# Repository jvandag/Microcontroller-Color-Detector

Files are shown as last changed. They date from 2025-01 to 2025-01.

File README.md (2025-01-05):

# Microcontroller-Color-Detector
Detects the color of physical objects using a phototransistor and simple machine learning.

## Pre-trained Example
Once the color detector has a full set of training data the user can scan a color using the blue button. The scan data is then compared against the training data to find the closest color match.

https://github.com/user-attachments/assets/66921391-efe7-4fe2-914a-f40178192495

## Training menu
The prompt to swap to training mode can be entered by pressing the yellow button. Once in training mode, additional samples may be taken the same way you would scan a color with the blue button. While in training mode, both buttons may be pressed at once to prompt deleting the stored training data. Each color requires 12 samples to function properly. If scanning/ready mode is entered when there is not sufficient training data, a message will display the colors that need more samples. 

https://github.com/user-attachments/assets/d95f9c35-6fea-4ae8-9513-e3b5f32a4a7d

## Circuit Diagram
The following circuit diagram is the one used in the example videos. Most microcontrollers that can run arduino code and have sufficient memory as well as two processing cores should have no problem replacing the [Adafruit ESP32 Feather V2]([url](https://learn.adafruit.com/adafruit-esp32-feather-v2)) that was used in the example. 

**Some things to note if using a different microcontroller:**
- Your analog resolution may be different so make sure to set the [ANALOG_RES]([url](https://github.com/jvandag/Microcontroller-Color-Detector/blob/ead716868bf5c02b5b45c210d8dfff97584aa8df/protos_and_consts.h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)) macro to your microcontroller's analog resolution.
- The example microcontroller has an internal pull up and pull down buttons that don't have resistors on the ground path. This is fine in this case but make sure that this wont fry your microcontroller or use pull down resistors.
- You may also have a similar problem with the LEDs. The out put on the example microcontroller output 3.3V to each LED which is a little high for some of them. You definitely should use resistors here if you have a higher voltage microcontroller.

Lastly, the 4 mega-ohm pull down on the photo transistor should be adjusted to fit your particular 3D print and microcontroller. If you find your phototransistor readings are too high, use a smaller pull down resistance. __I would highly recommend design your own case instead of using the stl files in this repository.__ The model is a bit small making it difficult to fit all of the components into the case and uncomfortable to hold the device as the grip area is too small. Additionally, bottom section that shields the transistor from external light is to long. In the example videos this section was 3mm from the paper to where the phototransistor was mounted, using a smaller distance would provide better readings, especially if you're using regular LEDs like the example.

circuit_diagram

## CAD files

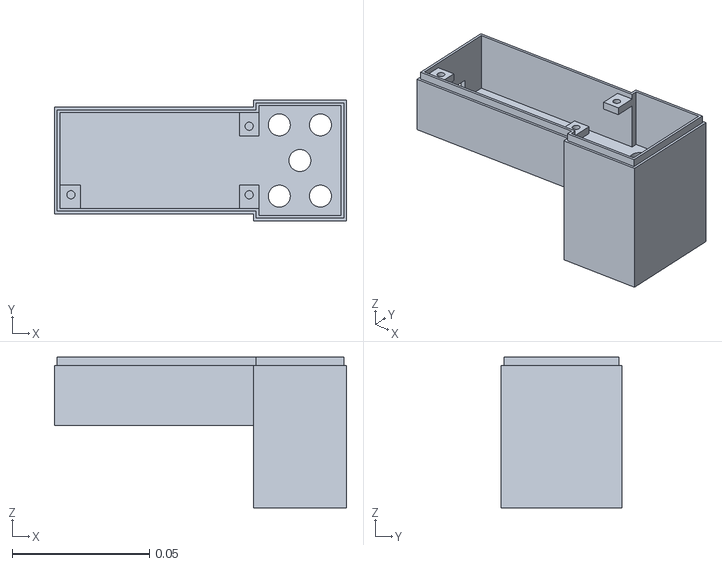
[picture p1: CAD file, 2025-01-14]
case_bottom.stl
0.106 x 0.044 x 0.055

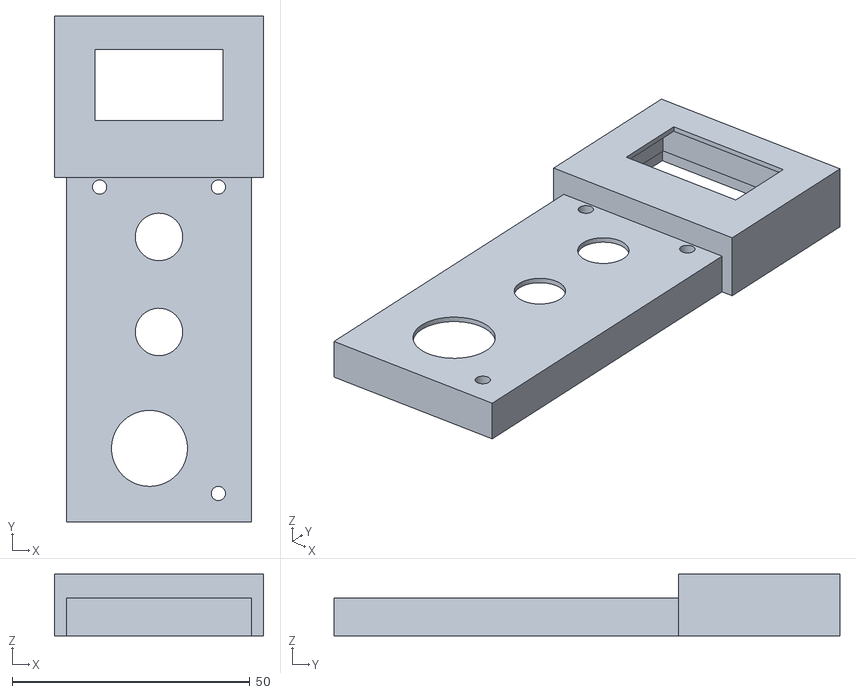
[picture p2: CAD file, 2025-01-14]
case_top.stl
44.0 x 106.5 x 13.0

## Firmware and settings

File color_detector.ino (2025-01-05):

#include <Adafruit_GFX.h>
#include <Adafruit_SSD1306.h>
#include <SPI.h>
#include <SD.h>
#include <math.h>
#include "protos_and_consts.h"
#include "screen_bitmaps.h"

// User Input
int selectPos    = 1024 * (analogRead(POTENTIOMETER_PIN)) / ANALOG_RES;
bool btn1Val     = true; // false when pressed (pull down btn)
bool btn2Val     = true; // false when pressed (pull down btn)
bool btn1LastVal = true; 
bool btn2LastVal = true;

//OLED SCREEN PARAMETERS
int LOADING_FRAME_COUNT = (sizeof(loading_frames) / sizeof(loading_frames[0]));

Adafruit_SSD1306 display(128, 64, &Wire, OLED_RST_PIN);

unsigned long t;
unsigned long time_checkpoint;
int loadingMenuFrame  = 0;
int textX = 0, textY  = 0;  // Text position
String text           = "";
bool select_screen    = true;
bool scrolling        = false;
bool scroll_end       = true;
bool scroll_start     = true;
int current_menu      = 0;
bool YesNoSel         = false;
int charWidth         = 6; 


// MISC
String logMsg                   = "";
bool quit                       = false;
int lastTrainedColor            = -1;
unsigned long lastLogMsgUpdate  = -1;
bool awaitingUsrSel             = false;
String notEnoughSamples         = "";
int pot_val;


// Data Containers

//Indicates wether each category has enough samples
int sampleCounts[8] = {0};

struct sample {
  //A sample of the values read by the phototransistor from the colored LEDs
  unsigned int groupValue : 3;            //We only need 3 bits to categorize 6 groups
  uint8_t colorValues[NUM_COLOR_VALUES];
  unsigned int distance : 11;             //The biggest distance can be 2046 units

  //Overloading the equal operator to set all values of one sample equal to another sample
  sample &operator=(const sample &s) {
    for (int a = 0; a < NUM_COLOR_VALUES; a++) {
      colorValues[a] = s.colorValues[a];
    }
    distance = s.distance;
    groupValue = s.groupValue;
    return *this;
  }
};

struct Group {
  unsigned int id : 3;         //There are only 8 groups, so we only need 3 bits
  unsigned int frequency : 4;  //We're limiting it to 12 samples per group, and 4 bits give us 15
};

struct {
  //Used to keep track of global memory in a tight compartment
  unsigned char trainingModeActive : 1;  //Basically a boolean
  unsigned char currentlyReading : 1;    //Debounce for button press
  unsigned char loadingRequired : 1;     //When we flip the toggle switch to sampling, we need to load the data
  unsigned int selectedGroupId : 4;      //What's the potentiometer pointing to?
  sample trainingData[8 * SAMPLES_PER_GROUP];
} colorDetector;



// Creating a process for each core
TaskHandle_t DisplayLoopHandle = NULL;
TaskHandle_t DataProcessingLoopHandle = NULL;

void setup() {
  Serial.begin(9600);
  while (!Serial) {
    delay(10);
  }
  pinMode(BTN1, INPUT_PULLUP);
  pinMode(BTN2, INPUT_PULLUP);
  pinMode(POTENTIOMETER_PIN, INPUT);
  pinMode(PHOTOTRANSISTOR_PIN, INPUT);
  pinMode(YELLOW_LED, OUTPUT);
  pinMode(GREEN_LED, OUTPUT);
  pinMode(RED_LED, OUTPUT);
  pinMode(BLUE_LED, OUTPUT);

  if (!SD.begin(CS_PIN)) {
    Serial.println("Card Mount Failed");
    return;
  } else {
    getDataFromCard();
    listDir(SD, "/", 0);
  }

  pot_val = analogRead(POTENTIOMETER_PIN);
  colorDetector.trainingModeActive = 0;
  checkMinNumSamples();
  current_menu = READY;

  // Create tasks and pin them to specific cores
  xTaskCreatePinnedToCore(
    displayLoop,          // Task function
    "Display Loop Task",  // Name of the task
    12000,                // Stack size for the task in words (num bytes / 4)
    NULL,                 // Parameter to pass to the task
    2,                    // Task priority
    &DisplayLoopHandle,   // Task handle
    1                     // Core ID (1 for Core 1)
  );

  xTaskCreatePinnedToCore(processingLoop, "Data Processing Loop Task", 12000, NULL, 2, &DataProcessingLoopHandle, 0);
}

void loop() {}

void displayLoop(void *parameter) {
  if (!display.begin(SSD1306_SWITCHCAPVCC, SCREEN_I2C_ADDR)) {
    Serial.println("SSD1306 allocation failed");
    vTaskDelete(NULL);  // End the task if display initialization fails
  }

  String t_text = "Training:";
  int offset;
  
  while (true) {
    display.clearDisplay();
    t = millis();
    pot_val = analogRead(POTENTIOMETER_PIN);

    if (colorDetector.trainingModeActive && !awaitingUsrSel && current_menu != LOADING) {
      if (t - lastLogMsgUpdate < 2000 && logMsg.length() > 0) {
        drawTextAtPosition(0, 0, logMsg, true, 1.5);
      }
      else if (colorDetector.trainingModeActive && current_menu != LOADING) {
        drawTextAtPosition(0, 0, t_text, true, 1.5);
      }
    }
    switch (current_menu) {
      case DET_BLACK:
      case DET_WHITE: 
      case DET_RED:
      case DET_ORANGE:
      case DET_YELLOW:
      case DET_GREEN:
      case DET_BLUE:
      case DET_PURPLE:
        displayDetColorText();
        break;
      case READY:
        displayReady();
        break;
      case ENABLE_TRAINING:
      case DISABLE_TRAINING:
      case DEL_TRAINING:
        displayYesNoOpt();
        break;
      case COLOR_LOGGED:
      case COLOR_SEL: 
        offset = getOffset(selectPos);
        drawSelMenuSlice(offset);
        break;
      case LOADING:
        displayLoading();
        break;
      default: break;
    }

    display.display();
    // Delay to yield to the OS and avoid watchdog issues
    vTaskDelay(15 / portTICK_PERIOD_MS);
  }
}

void processingLoop(void *parameter) {
  bool btn1LastState = true;
  bool btn2LastState = true;

  while(true) {
    btn1Val = digitalRead(BTN1);
    btn2Val = digitalRead(BTN2);

    if(awaitingUsrSel) {
      if(!btn1Val && btn1LastState) {
        if (YesNoSel) {
          switch(current_menu) {
            case ENABLE_TRAINING:
            case DISABLE_TRAINING:
              checkMinNumSamples();
              colorDetector.trainingModeActive = !colorDetector.trainingModeActive;
              current_menu = colorDetector.trainingModeActive ? COLOR_SEL : READY;
              break;
            case DEL_TRAINING: 
              deleteTraining(SD);
              colorDetector.trainingModeActive = 1;
              current_menu = COLOR_SEL;
              break;
            default: 
              current_menu = COLOR_SEL;
              break;
          }
          
        }
        else current_menu = colorDetector.trainingModeActive ? COLOR_SEL : READY;
        awaitingUsrSel = false;
      }
      else if (!btn2Val && btn2LastState) {
        current_menu = colorDetector.trainingModeActive ? COLOR_SEL : READY;
        awaitingUsrSel = false;
      }
      btn1LastState = btn1Val;
      btn2LastState = btn2Val;
      continue;
    }
    
    // If one button is pressed wait a moment to see if the user is
    // trying to press both buttons at once
    if(btn1Val && !btn2Val) {
      vTaskDelay(100 / portTICK_PERIOD_MS);
      btn1Val = digitalRead(BTN1);
    }
    else if (!btn1Val && btn2Val) {
      vTaskDelay(100 / portTICK_PERIOD_MS);
      btn2Val = digitalRead(BTN2);
    }
    
    if (current_menu != LOADING && btn1Val && !btn2Val && btn2LastState) {
      //change bring up toggle training mode menu
      current_menu = (colorDetector.trainingModeActive || current_menu == DISABLE_TRAINING) ? DISABLE_TRAINING : ENABLE_TRAINING;
      awaitingUsrSel = true;
      btn1LastState = btn1Val;
      btn2LastState = btn2Val;
      //add delay between checks
      vTaskDelay(15 / portTICK_PERIOD_MS);
      continue;
    }
    else if (current_menu != LOADING && colorDetector.trainingModeActive && !btn1Val && !btn2Val) {
      //change bring up toggle training mode menu
      current_menu = DEL_TRAINING;
      awaitingUsrSel = true;
      btn1LastState = btn1Val;
      btn2LastState = btn2Val;
      //add delay between checks
      vTaskDelay(15 / portTICK_PERIOD_MS);
      continue;
    }

    if (!btn1Val && btn1LastState && !colorDetector.currentlyReading && !scrolling) {
      if (colorDetector.trainingModeActive) {
        colorDetector.currentlyReading = 1;
        current_menu = LOADING;
        //When we click the button we will store the data into the selected group's file on the SD card
        const String path = String("/") + String(colorDetector.selectedGroupId) + String(".txt");
        //Since we added to the training data, we need to load that new data next time we sample
        colorDetector.loadingRequired = 1;
        //Write color data to SD card in RGBY order
        writeColor(RED_LED, SD);
        writeColor(GREEN_LED, SD);
        writeColor(BLUE_LED, SD);
        writeColor(YELLOW_LED, SD);
        appendFile(SD, path, "\n");

        sampleCounts[colorDetector.selectedGroupId]++;

        // Sleep to let our nice loading animation play for a moment :')
        vTaskDelay(LOADING_DELAY / portTICK_PERIOD_MS);
        current_menu = COLOR_SEL;
        lastLogMsgUpdate = millis();
        logMsg = color2Txt(colorDetector.selectedGroupId) + " Sample Logged!";
      } 
      else if (notEnoughSamples == "") {
        //When we click the button we will compare the sample data to the training data
        current_menu = LOADING;

        sample newSample;
        Serial.printf("Red ");
        newSample.colorValues[0] = readColor(RED_LED);
        Serial.printf("Green ");
        newSample.colorValues[1] = readColor(GREEN_LED);
        Serial.printf("Blue ");
        newSample.colorValues[2] = readColor(BLUE_LED);
        Serial.printf("Yellow ");
        newSample.colorValues[3] = readColor(YELLOW_LED);
        //If we haven't added anything new to the training data, we don't need to read from the SD card again
        if (colorDetector.loadingRequired) {
          //Take the training data from the SD card and put it into the trainingData array
          getDataFromCard();
          colorDetector.loadingRequired = 0;
        }
        //Now we use the classify() function to determine what color newSample is... but how many neighbors should we look at?
        //Typically you can get away with setting k to the square root of the total number of datapoints. In our case k=sqrt(8*12)
        int newSample_groupId = classify(colorDetector.trainingData, 8 * SAMPLES_PER_GROUP, 9, newSample);

        // Sleep to let our nice loading animation play for a moment :')
        vTaskDelay(LOADING_DELAY / portTICK_PERIOD_MS);
        current_menu = newSample_groupId;
        vTaskDelay(2000 / portTICK_PERIOD_MS);
        current_menu = READY;
      }
      colorDetector.currentlyReading = 0;
    }
    btn1LastState = btn1Val;
    btn2LastState = btn2Val;

    //loop delay
    vTaskDelay(10 / portTICK_PERIOD_MS);
  }
}

void checkMinNumSamples() {
  String lastColor = "";
  notEnoughSamples = "";
  int notEnoughCount = 0;

  for (int i = 0; i < 8; i++) {
    if (sampleCounts[i] < 12) {
      // If there are already elements in notEnoughSamples, handle commas and spaces
      if (notEnoughCount > 0) {
        if (notEnoughCount == 1) {
          notEnoughSamples += lastColor; // Add the first color without a comma
        } else {
          notEnoughSamples += ", " + lastColor; // Add comma for subsequent colors
        }
      }
      lastColor = color2Txt(i); // Update lastColor to the current color
      notEnoughCount++;
    }
  }

  // Handle final addition with "and"
  if (notEnoughCount > 1) {
     if (notEnoughCount == 2) {
      // No comma for exactly two entries
      notEnoughSamples += " and " + lastColor;
    } else {
      notEnoughSamples += ", and " + lastColor;
    }
  } else if (notEnoughCount == 1) {
    notEnoughSamples = lastColor; // Only one entry
  }
}



void displayReady() {
  if (notEnoughSamples != "") {
    drawTextAtPosition(0, 0, "Low Sample Count!", true, 1.5);
    drawTextAtPosition(0, 16, "The following need\nmore samples:\n\n" + notEnoughSamples, false, 1.5);
  } else {
    drawTextAtPosition(0, 0, "Press the blue button", true, 1.5);
    drawTextAtPosition(0, 8, "to scan.", true, 1.5);
    drawTextAtPosition(14, 26, "Ready!", false, 3.5);
  }
}

void displayLoading() {
  display.drawBitmap(40, 16, loading_frames[loadingMenuFrame], FRAME_WIDTH, FRAME_HEIGHT, 1);
  drawTextAtPosition(0, 0, getProcessingString(loadingMenuFrame), false, 1.5);

  // Update loadingMenuFrame
  loadingMenuFrame = (loadingMenuFrame + 1) % LOADING_FRAME_COUNT;
  delay(FRAME_DELAY);
}

void displayYesNoOpt() {
  //logMsg = "";
  // Draw the Yes and No text
  display.drawBitmap(0, 0, epd_bitmap_YesNoBitmap, SCREEN_WIDTH, SCREEN_HEIGHT, SSD1306_WHITE);
  // Display prompt text
  String prompt = "";
  switch (current_menu) {
    case ENABLE_TRAINING: 
      prompt = "Enable Training Mode?";
      break;
    case DISABLE_TRAINING:
      prompt = "Disable Training\nMode?";
      break;
    case DEL_TRAINING:
      prompt = "Delete All Training\nData?";
      break;
    default:
      prompt = "Unknown Prompt";
      break;
  }
  drawTextAtPosition(0, 0, prompt, false, 1.5);

  // Set the highlight
  YesNoSel = pot_val % ((ANALOG_RES+1)/2) <= ANALOG_RES/4;
  int rectWidth = 36;
  int rectHeight = 23;
  int radius = 10;
  if (YesNoSel) display.drawRoundRect(14, 27, rectWidth, rectHeight, radius, SSD1306_WHITE);
  else display.drawRoundRect(78, 27, rectWidth, rectHeight, radius, SSD1306_WHITE);
}

void displayDetColorText() {
  // Set these to true to disable blinky arrows when we slice the bitmap
  scroll_start = true;
  scroll_end = true;
  // Enable rounded rectangle boarder around text
  scrolling = false;

  int dispNum = (0 <= current_menu && current_menu < 8) ? current_menu : 0;
  // Get the bit map offset for slicing the color text out of the map
  int offset = SCREEN_WIDTH * dispNum;
  // Finally draw the text
  drawSelMenuSlice(offset);
  drawTextAtPosition(0, 0, "Color Detected:", true, 1.5);
}

String color2Txt(int color) {
  switch(color) {
    case black:   return "Black";
    case white:   return "White";
    case red:     return "Red";
    case orange:  return "Orange";
    case yellow:  return "Yellow";
    case green:   return "Green";
    case blue:    return "Blue";
    case purple:  return "Purple";
  }
}

void changeColor(enum colors c) {
  colorDetector.selectedGroupId = c;
}

// Function to draw text at a specified position
void drawTextAtPosition(int x, int y, String txt, bool center = false, float size = 1.5) {
  if (center) x = (SCREEN_WIDTH-charWidth*(size /1.5)*txt.length())/2;
  display.setTextSize(size);
  display.setCursor(x, y);
  display.setTextColor(SSD1306_WHITE);
  display.print(txt);
}

// returns the processing loading text with an appropriate number of dots
String getProcessingString(int num_frames) {
  //TO DO: Change to use current millis() instead of loadingMenuFrame
  String loading_text = "Processing";
  for (int i = 0; i < ((int)(num_frames / 7)) % 4; i++) {
    loading_text += ".";
  }
  return loading_text;
}

int getOffset(int &selectPos) {
  int val = pot_val * SEL_MAP_WIDTH / ANALOG_RES;
  scroll_start = scroll_end = false;
  scrolling = true;
  if (val > 7 * SCREEN_WIDTH) {
    changeColor(purple);
    if (selectPos < 7 * SCREEN_WIDTH) selectPos = min(selectPos + SEL_SCROLL_SPD, 7 * SCREEN_WIDTH);
    else if (selectPos > 7 * SCREEN_WIDTH) selectPos = max(selectPos - SEL_SCROLL_SPD, 7 * SCREEN_WIDTH);
    if (selectPos == 7 * SCREEN_WIDTH) {
      time_checkpoint = millis();
      scrolling = false;
    }
    scroll_end = true;
    return selectPos;
  }
  if (val > 6 * SCREEN_WIDTH) {
    changeColor(blue);
    if (selectPos < 6 * SCREEN_WIDTH) selectPos = min(selectPos + SEL_SCROLL_SPD, 6 * SCREEN_WIDTH);
    else if (selectPos > 6 * SCREEN_WIDTH) selectPos = max(selectPos - SEL_SCROLL_SPD, 6 * SCREEN_WIDTH);
    if (selectPos == 6 * SCREEN_WIDTH) {
      time_checkpoint = millis();
      scrolling = false;
    }
    return selectPos;
  }
  if (val > 5 * SCREEN_WIDTH) {
    changeColor(green);
    if (selectPos < 5 * SCREEN_WIDTH) selectPos = min(selectPos + SEL_SCROLL_SPD, 5 * SCREEN_WIDTH);
    else if (selectPos > 5 * SCREEN_WIDTH) selectPos = max(selectPos - SEL_SCROLL_SPD, 5 * SCREEN_WIDTH);
    if (selectPos == 5 * SCREEN_WIDTH) {
      time_checkpoint = millis();
      scrolling = false;
    }
    return selectPos;
  }
  if (val > 4 * SCREEN_WIDTH) {
    changeColor(yellow);
    if (selectPos < 4 * SCREEN_WIDTH) selectPos = min(selectPos + SEL_SCROLL_SPD, 4 * SCREEN_WIDTH);
    else if (selectPos > 4 * SCREEN_WIDTH) selectPos = max(selectPos - SEL_SCROLL_SPD, 4 * SCREEN_WIDTH);
    if (selectPos == 4 * SCREEN_WIDTH) {
      time_checkpoint = millis();
      scrolling = false;
    }
    return selectPos;
  }
  if (val > 3 * SCREEN_WIDTH) {
    changeColor(orange);
    if (selectPos < 3 * SCREEN_WIDTH) selectPos = min(selectPos + SEL_SCROLL_SPD, 3 * SCREEN_WIDTH);
    else if (selectPos > 3 * SCREEN_WIDTH) selectPos = max(selectPos - SEL_SCROLL_SPD, 3 * SCREEN_WIDTH);
    if (selectPos == 3 * SCREEN_WIDTH) {
      time_checkpoint = millis();
      scrolling = false;
    }
    return selectPos;
  }
  if (val > 2 * SCREEN_WIDTH) {
    changeColor(red);
    if (selectPos < 2 * SCREEN_WIDTH) selectPos = min(selectPos + SEL_SCROLL_SPD, 2 * SCREEN_WIDTH);
    else if (selectPos > 2 * SCREEN_WIDTH) selectPos = max(selectPos - SEL_SCROLL_SPD, 2 * SCREEN_WIDTH);
    if (selectPos == 2 * SCREEN_WIDTH) {
      time_checkpoint = millis();
      scrolling = false;
    }
    return selectPos;
  }
  if (val > SCREEN_WIDTH) {
    changeColor(white);
    if (selectPos < SCREEN_WIDTH) selectPos = min(selectPos + SEL_SCROLL_SPD, SCREEN_WIDTH);
    else if (selectPos > SCREEN_WIDTH) selectPos = max(selectPos - SEL_SCROLL_SPD, SCREEN_WIDTH);
    if (selectPos == SCREEN_WIDTH) {
      time_checkpoint = millis();
      scrolling = false;
    }
    return selectPos;
  } else {
    changeColor(black);
    if (selectPos < 0) selectPos = min(selectPos + SEL_SCROLL_SPD, 0);
    else if (selectPos > 0) selectPos = max(selectPos - SEL_SCROLL_SPD, 0);
    if (selectPos == 0) {
      time_checkpoint = millis();
      scrolling = false;
    }
    scroll_start = true;
    return selectPos;
  }
}

void drawSelMenuSlice(int xOffset) {
  // Ensure xOffset is within bounds of the larger bitmap
  xOffset = min(max(xOffset, 0), SEL_MAP_WIDTH - SCREEN_WIDTH);

  // Buffer for the sliced 128x48 image
  uint8_t slicedBitmap[SCREEN_WIDTH * SCREEN_HEIGHT / 8];

  // Copy the relevant section from the larger bitmap to the sliced bitmap
  for (int y = 0; y < SCREEN_HEIGHT; y++) {
    int sourceIndex = y * (SCREEN_WIDTH) + (xOffset / 8);  // Start byte of the row in the larger bitmap
    int targetIndex = y * (SCREEN_WIDTH / 8);          // Start byte of the row in the sliced bitmap

    // Copy exactly 16 bytes (128 pixels) for each row
    memcpy(&slicedBitmap[targetIndex], &epd_bitmap_color_sel_screen_bitmap[sourceIndex], SCREEN_WIDTH / 8);
  }

  // Draw the sliced bitmap on the display
  display.drawBitmap(0, 0, slicedBitmap, SCREEN_WIDTH, SCREEN_HEIGHT, SSD1306_WHITE);

  if (!scrolling) {
    // Define dimensions for the rectangle loadingMenuFrame
    int rectWidth = 94;   // Width of the rectangle
    int rectHeight = 40;  // Height of the rectangle
    int radius = 10;

    // Calculate the top-left corner to center the rectangle
    int x = (SCREEN_WIDTH - rectWidth) / 2;
    int y = (SCREEN_HEIGHT - rectHeight + 9) / 2;

    // Draw the rounded rectangle
    display.drawRoundRect(x, y, rectWidth, rectHeight, radius, SSD1306_WHITE);

    if (time_checkpoint % 1500 > 700) {
      int arrowSize = 6;                    // Size of the arrow head
      int yCenter = SCREEN_HEIGHT / 2 + 4;  // Center of the screen vertically

      if (!scroll_start) {
        // Draw < symbol on the left side
        display.drawLine(0, yCenter, 0 + arrowSize, yCenter - arrowSize, SSD1306_WHITE);  // Left top line
        display.drawLine(0, yCenter, 0 + arrowSize, yCenter + arrowSize, SSD1306_WHITE);  // Left bottom line
      }

      if (!scroll_end) {
        // Draw > symbol on the right side
        display.drawLine(SCREEN_WIDTH - 1, yCenter, SCREEN_WIDTH - 1 - arrowSize, yCenter - arrowSize, SSD1306_WHITE);  // Right top line
        display.drawLine(SCREEN_WIDTH - 1, yCenter, SCREEN_WIDTH - 1 - arrowSize, yCenter + arrowSize, SSD1306_WHITE);  // Right bottom line
      }
    }
  }
}

void insertionSort(sample arr[], int n) {
  // Copied and modified from GeeksForGeeks.com
  int i, key, j;
  for (i = 1; i < n; i++) {
    key = arr[i].distance;
    j = i - 1;

    while (j >= 0 && arr[j].distance > key) {
      sample temp = arr[j + 1];
      arr[j + 1] = arr[j];
      arr[j] = temp;
      j = j - 1;
    }
    arr[j + 1].distance = key;
  }
}

// Gets the biggest difference in color value
// Was found to work the best in my use case but suming all the differences in RGBY values
// will likely work better in most cases
unsigned int maxColorValueDistance(const sample &s1, const sample &s2) {
  unsigned int maxDifference = 0;
  for (int i = 0; i < 4; ++i) { // Assuming there are 4 color values
    unsigned int diff = std::abs(static_cast<int>(s1.colorValues[i]) - static_cast<int>(s2.colorValues[i]));
    if (diff > maxDifference) {
      maxDifference = diff;
    }
  }
  return maxDifference;
}
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

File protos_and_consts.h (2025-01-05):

#ifndef _PROTOS_AND_CONSTS_H
#define _PROTOS_AND_CONSTS_H

// PINs
#define BTN1 14 // K10 on board
#define BTN2 15 // M10 on board
#define POTENTIOMETER_PIN 13 // A12, Q1 on board
#define PHOTOTRANSISTOR_PIN A3
//#define BUTTON_PIN 2
#define RED_LED 33 
#define YELLOW_LED 12
#define GREEN_LED 27
#define BLUE_LED 25
//#define TOGGLE_SWITCH_PIN 19 //A5
#define OLED_RST_PIN -1  // Reset pin (-1 if not available)
#define CS_PIN 4 // SD card chip select


// OLED SCREEN PARAMETERS
#define SCREEN_I2C_ADDR 0x3C // or 0x3C
#define SCREEN_WIDTH 128     // OLED display width, in pixels
#define SCREEN_HEIGHT 64     // OLED display height, in pixels
#define FRAME_DELAY 42
#define FRAME_WIDTH 48
#define FRAME_HEIGHT 48
#define SEL_SCROLL_SPD 12
#define SEL_MAP_WIDTH 1024
#define SEL_SCR_COUNT 8

// MISC
#define ANALOG_RES 4095
#define LOADING_DELAY 1500
#define SAMPLES_PER_GROUP 12
#define NUM_COLOR_VALUES 4 //Red, blue, green, and yellow values


enum menus {
  DET_BLACK,
  DET_WHITE,
  DET_RED,
  DET_ORANGE,
  DET_YELLOW,
  DET_GREEN,
  DET_BLUE,
  DET_PURPLE,
  READY,
  ENABLE_TRAINING,
  DISABLE_TRAINING,
  DEL_TRAINING,
  COLOR_SEL,
  LOADING,
  COLOR_LOGGED,
};

enum colors {
  black,
  white,
  red,
  orange,
  yellow,
  green,
  blue,
  purple
};

// Checks if each color has atleast the minimum number of samples needed.
// Sets the string notEnoughSamples to a list of the groups that don't ahve enough samples
void checkMinNumSamples();

// Displays the loading screen
void displayLoading();

// displays the ready to scan screen
void displayReady();

// Returns the string name of the enum color
String color2Txt(int color);

// Sets the display to be a yes no option menu with prompt text based on the current_menu variable
void displayYesNoOpt();

// Sets the display to show the appropriate slice of the select menu bitmap when detecting a color
void displayDetColorText();

// Deletes a file at the given path
void deleteFile(fs::FS &fs, const String &path);

// Appends to the file at the given path, creates a new file if the file doesn't exist
void appendFile(fs::FS &fs, const String &path, const String &message);

// Overwrites a file at the given path, creates a new file if the file doesn't exist
void writeFile(fs::FS &fs, const char *path, const char *message);

// Lists the files in a directory on the SD card
void listDir(fs::FS &fs, const char *dirname, uint8_t levels);

// Gathers and writes color training data to the SD card
void writeColor(int pin, fs::FS &SD);

// Similar to writeColor() but doesn't write to the SD card
int readColor(int pin);

// Returns the number of digits in an integer
int getNumDigits(int num);

// Updates the current menu to prompt displayLoop to change the display to the color
void displayColor(colors color);

// Retrieves training data from the SD card and loads it into colorDetector.trainingData
void getDataFromCard();

/*
The classify() function utilizes the KNN algorithm
k is the number of nearby neighbors
*/
int classify(struct sample arr[], int numTrainingSamples, int k, const sample node);

//Takes two colorValue arrays and finds the distance between each color value.
//We're using the formula d=sqrt(sum((pixel_1 - pixel_2)^2))
unsigned int colorValueDistance(const sample s1, sample s2);

// inserstion sort for the passed in sample array
void insertionSort(sample arr[], int n);

// Changes the color of the display elements based on the provided enum value
void changeColor(enum colors c);

// Draws text at a specified position on the display
void drawTextAtPosition(int x, int y, String txt, bool center, float size);

// Generates a processing string with dynamic ellipsis based on frame count
String getProcessingString(int num_frames);

// Calculates the offset based on POTENTIOMETER_PIN value and adjusts the selection position
int getOffset(int &selectPos);

// The display loop that runs on a separate core from the processing loop.
void displayLoop(void* parameter);

// The processing loop that runs on a separate core from the display loop.
void processingLoop(void* parameter);

// Subsections the bitmap used for the training menu select options
void drawSelMenuSlice(int xOffset);

#endif //_PROTOS_AND_CONSTS_H
